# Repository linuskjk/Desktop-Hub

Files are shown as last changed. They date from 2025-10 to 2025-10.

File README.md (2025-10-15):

# Desktop Hub

What this project is
--------------------
This project is a compact desktop USB 2.0 hub built around the GL852G hub controller. It gives you:
- One USB-C upstream port (to connect to a host)
- Two USB-A downstream ports plus one USB-C downstream port
- Per-port power switches (TPS2051C) to protect and limit current to each downstream port
- ESD protection on USB data and power lines

Why I want to build it   I-
----------------------
- Want a small, DIY USB hub for flash drives, keyboards, mice, and low-power peripherals
- Need a hub you can modify (change ESD parts, use different power switches, or tweak traces for higher current)
- Learn about hub controllers, USB signal routing, and SMD assembly

Quick features and limits
-------------------------
- USB 2.0 data speeds supported (Full Speed/High Speed up to USB 2.0 limits)
- Signal traces for D+/D− are routed at 0.2 mm (fine and short — good for USB 2.0)
- VBUS/GND are routed at 0.2 mm in this version due to spacing problems— suitable for flash drives and low-current devices; phone charging will be limited

Licensing
---------
This project is released under the MIT License.

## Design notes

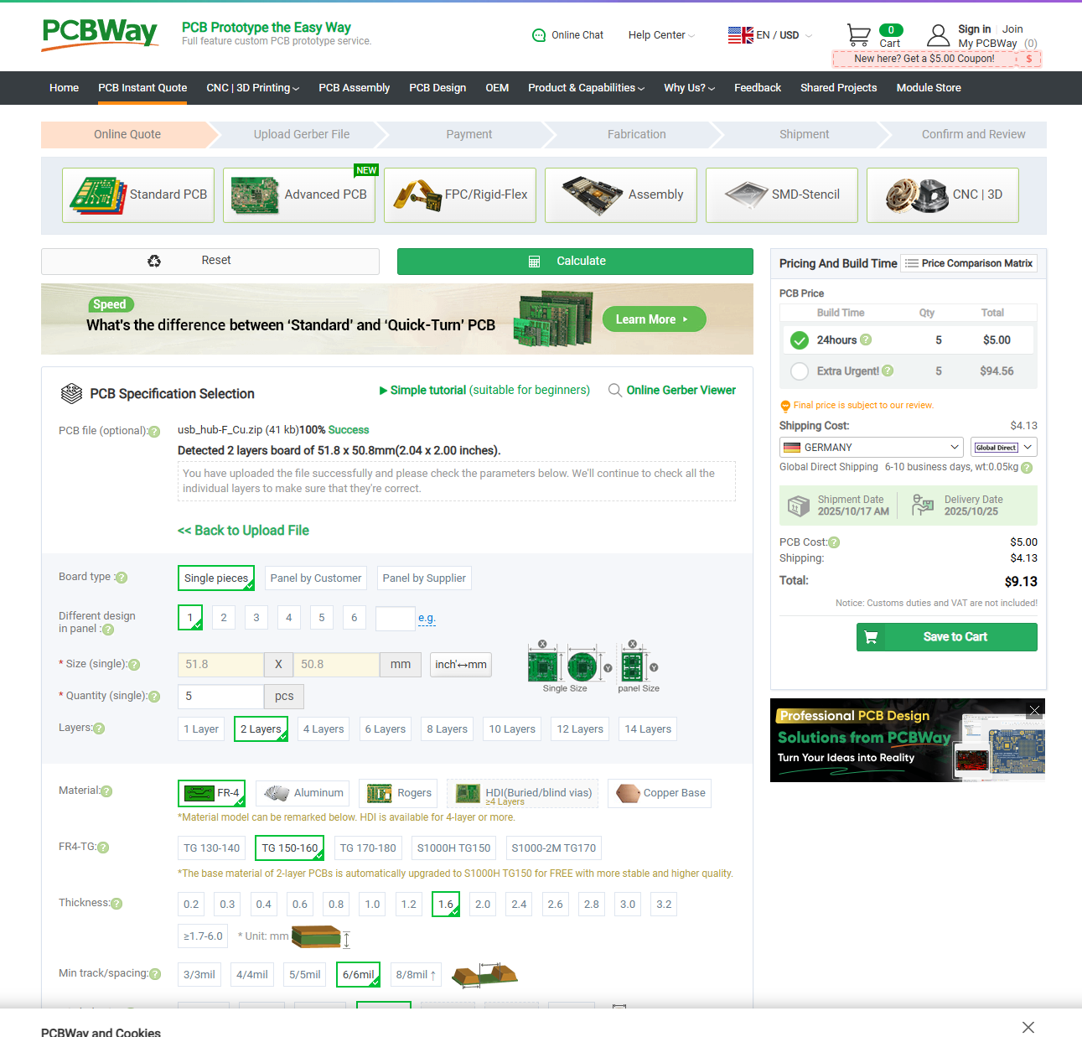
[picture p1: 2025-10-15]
price screenshots/pcb.png

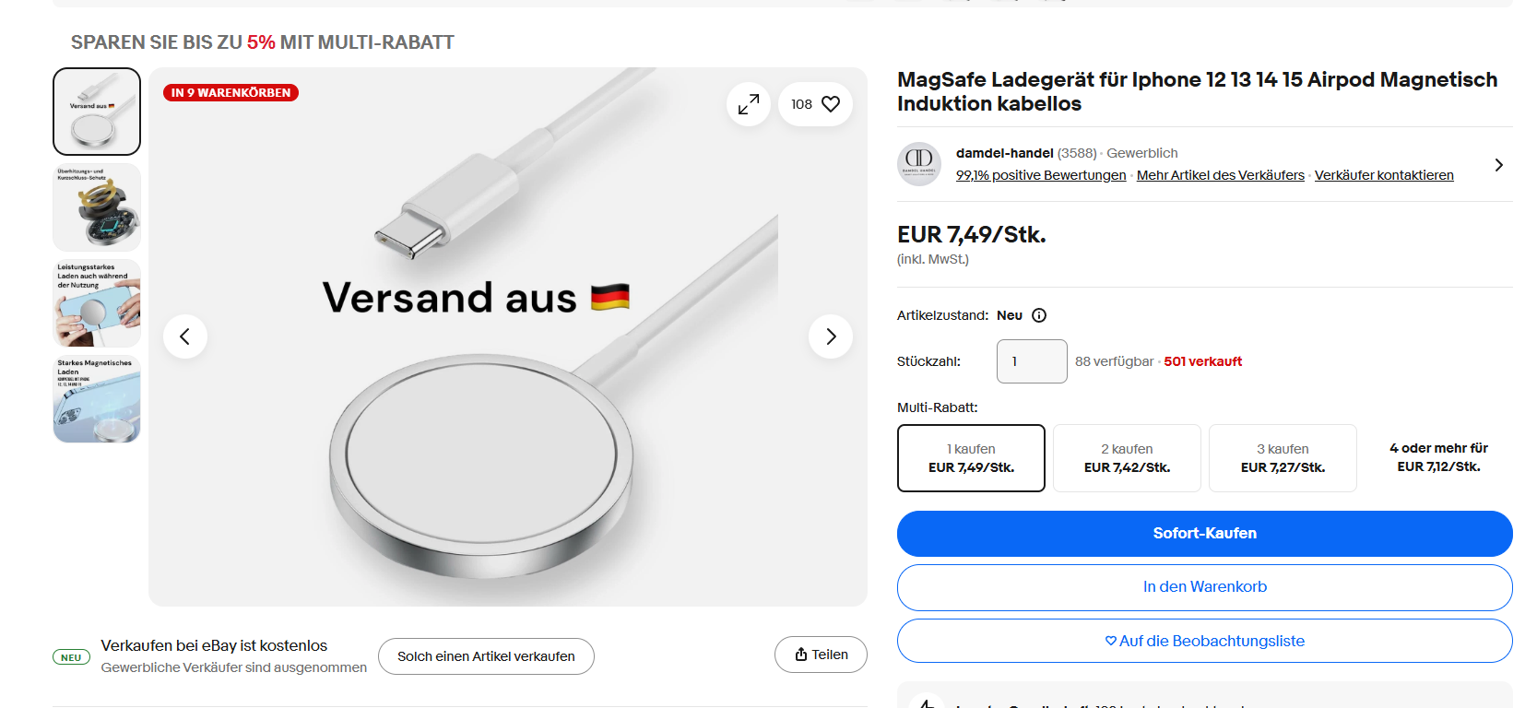
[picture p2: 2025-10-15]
price screenshots/magsafe.png

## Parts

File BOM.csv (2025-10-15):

Reference | Qty | Value / Description | DNP | Exclude from BOM | Exclude from Board | Footprint | Datasheet | Notes
C1 | 1 | 10uF |  |  |  | Capacitor_SMD:C_0805_2012Metric_Pad1.18x1.45mm_HandSolder | ~ | As on schematic
C2 | 1 | 0.1uF |  |  |  | Capacitor_SMD:C_0805_2012Metric_Pad1.18x1.45mm_HandSolder | ~ | As on schematic
C3 | 1 | 1uF |  |  |  | Capacitor_SMD:C_0603_1608Metric_Pad1.08x0.95mm_HandSolder | ~ | As on schematic
C4 | 1 | 10uF |  |  |  | Capacitor_SMD:C_0805_2012Metric_Pad1.18x1.45mm_HandSolder | ~ | As on schematic
C5,C7,C9,C12,C13,C14,C15,C16,C17,C18,C19,C20,C21,C22,C23 | 15 | 0.1uF |  |  |  | Capacitor_SMD:C_0603_1608Metric_Pad1.08x0.95mm_HandSolder | ~ | Bulk decoupling
C6,C8 | 2 | 0.1uF |  |  |  | Capacitor_SMD:C_0805_2012Metric_Pad1.18x1.45mm_HandSolder | ~ | As on schematic
C10,C11 | 2 | 222pF |  |  |  | Capacitor_SMD:C_0603_1608Metric_Pad1.08x0.95mm_HandSolder | ~ | Crystal loading
F1 | 1 | Polyfuse 1206 |  |  |  | Fuse:Fuse_1206_3216Metric_Pad1.42x1.75mm_HandSolder | ~ | VBUS overcurrent protection
FB1 | 1 | Ferrite Bead 0805 |  |  |  | Inductor_SMD:L_0805_2012Metric_Pad1.15x1.40mm_HandSolder | ~ | EMI on VBUS
H1 | 1 | MountingHole |  | Excluded from BOM |  |  |  | Mechanical hole (NPTH)
J1,J2 | 2 | USB_C_Receptacle_USB2.0_16P |  |  |  | Connector_USB:USB_C_Receptacle_HRO_TYPE-C-31-M-12 | https://www.usb.org/sites/default/files/documents/usb_type-c.zip | Upstream and downstream USB-C
J3,J4 | 2 | USB_A |  |  |  | Connector_USB:USB_A_Stewart_SS-52100-001_Horizontal | ~ | USB-A downstream ports
R1,R2,R7,R8 | 4 | 5.1k |  |  |  | Resistor_SMD:R_0603_1608Metric_Pad0.98x0.95mm_HandSolder | ~ | Pull-downs/dividers
R3,R4,R9,R10,R11,R12,R13,R14 | 8 | 27 |  |  |  | Resistor_SMD:R_0603_1608Metric_Pad0.98x0.95mm_HandSolder | ~ | Pull-downs
R5 | 1 | 12k |  |  |  | Resistor_SMD:R_0603_1608Metric_Pad0.98x0.95mm_HandSolder | ~ | Net resistors
R6 | 1 | 10k |  |  |  | Resistor_SMD:R_0603_1608Metric_Pad0.98x0.95mm_HandSolder | ~ | Pull-up
U1,U7,U8,U9 | 4 | USBLC6-2SC6 (ESD Diode) |  |  |  | Package_TO_SOT_SMD:SOT-23-6 | https://www.st.com/resource/en/datasheet/usblc6-2.pdf | USB ESD protection
U2 | 1 | AP2112K-3.3 (LDO) |  |  |  | Package_TO_SOT_SMD:SOT-23-5 | https://www.diodes.com/assets/Datasheets/AP2112.pdf | 3.3V regulator
U3,U4 | 2 | TPS2051CDBV (USB power switch) |  |  |  | Package_TO_SOT_SMD:SOT-23-5 | https://www.ti.com/lit/ds/symlink/tps2051c.pdf | Per-port power switch
U5 | 1 | GL852G (LQFP-48) hub controller |  |  |  | Package_QFP:LQFP-48_7x7mm_P0.5mm |  | Verify footprint and paste
U6 | 1 | TPS2051CDBV (USB power switch) |  |  |  | Package_TO_SOT_SMD:SOT-23-5_HandSoldering | https://www.ti.com/lit/ds/symlink/tps2051c.pdf | Per-port power switch
Y1 | 1 | 12MHz Crystal 5032 |  |  |  | Crystal:Crystal_SMD_5032-2Pin_5.0x3.2mm_HandSoldering | ~ | Hub clock
# Additional non-PCB items and accessories (not mounted on PCB)
USB-C upstream cable | 1 | USB-C to USB-A (or C-to-C) cable |  | Exclude from BOM |  | Cable | ~ | Use appropriate cable for host connection (choose C-to-C for modern hosts)
MagSafe adapter (external) | 1 | Apple MagSafe adapter or magnetic power adapter (optional) |  | Exclude from BOM |  | Accessory | ~ | Optional external magnetic power adapter; verify model compatibility – not a PCB part
5V DC power adapter (optional) | 1 | 5V 2A power supply (if using external power) |  | Exclude from BOM |  | Accessory | ~ | Optional external power supply for VBUS when used standalone

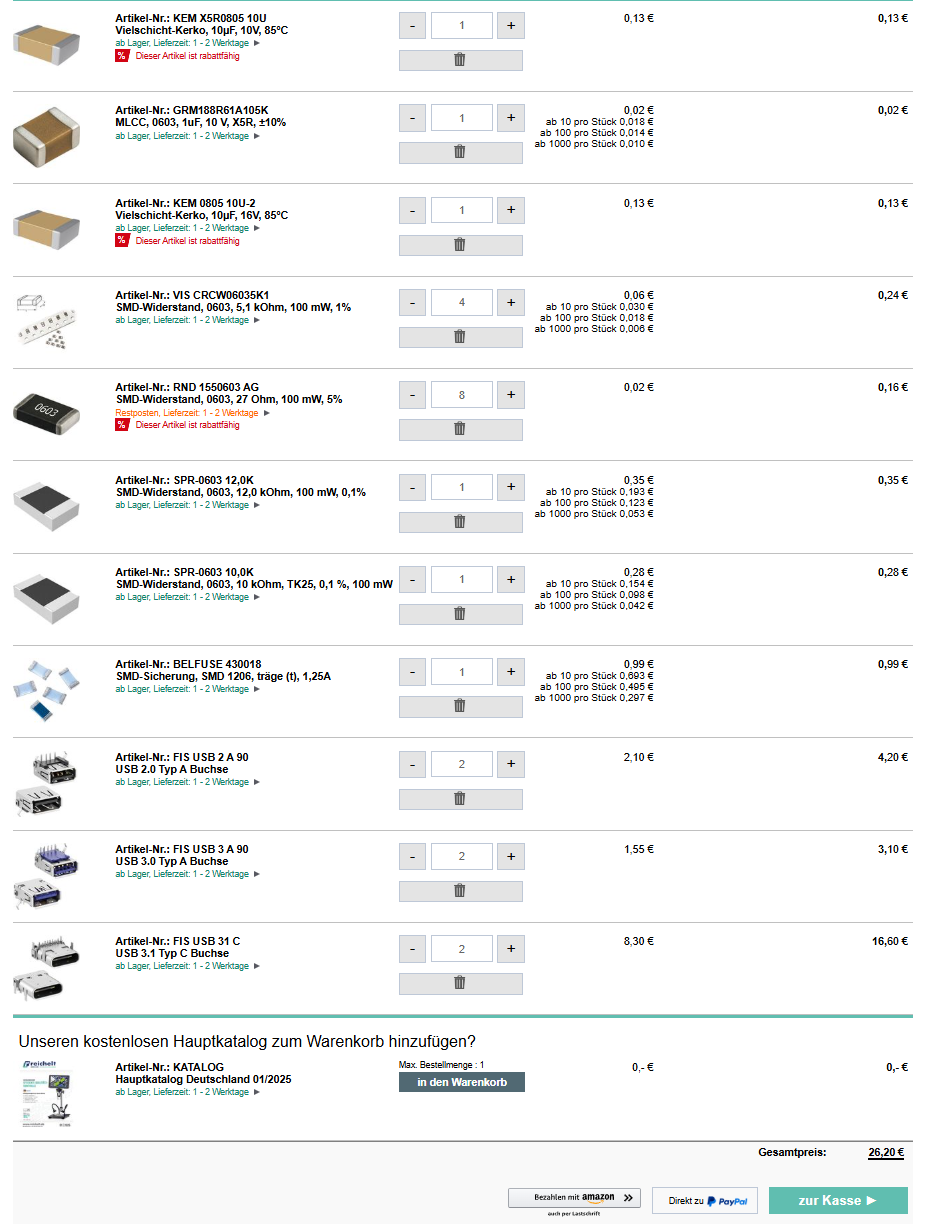
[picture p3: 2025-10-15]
price screenshots/pcb-parts-1.png

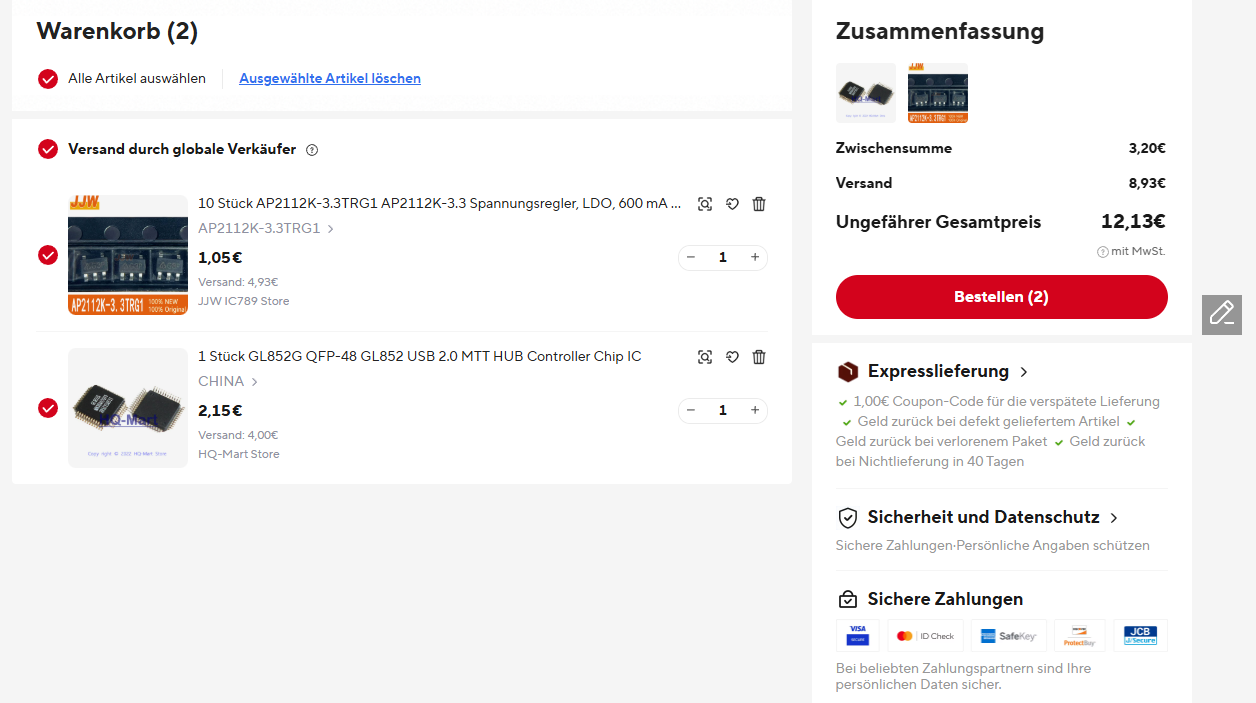
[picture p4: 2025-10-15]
price screenshots/pcb-parts-2.png

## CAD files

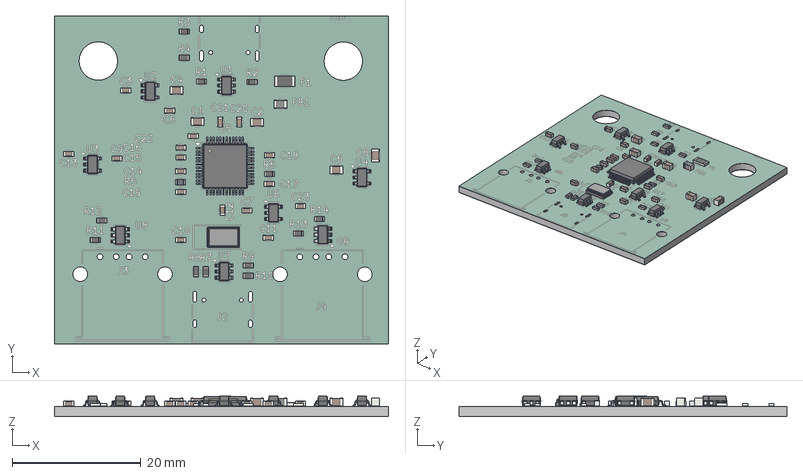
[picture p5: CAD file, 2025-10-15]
pcb.step
51.8 x 50.8 x 3.19 mm
C_0603_1608Metric x 18
R_0603_1608Metric x 14
Crystal_SMD_5032-2Pin_5.0x3.2mm
SOT-23-5 x 4
L_0805_2012Metric
C_0805_2012Metric x 5
SOT-23-6 x 4
LQFP-48_7x7mm_P0.5mm
Fuse_1206_3216Metric
usb_hub_silkscreen
usb_hub_soldermask x 2
usb_hub_PCB

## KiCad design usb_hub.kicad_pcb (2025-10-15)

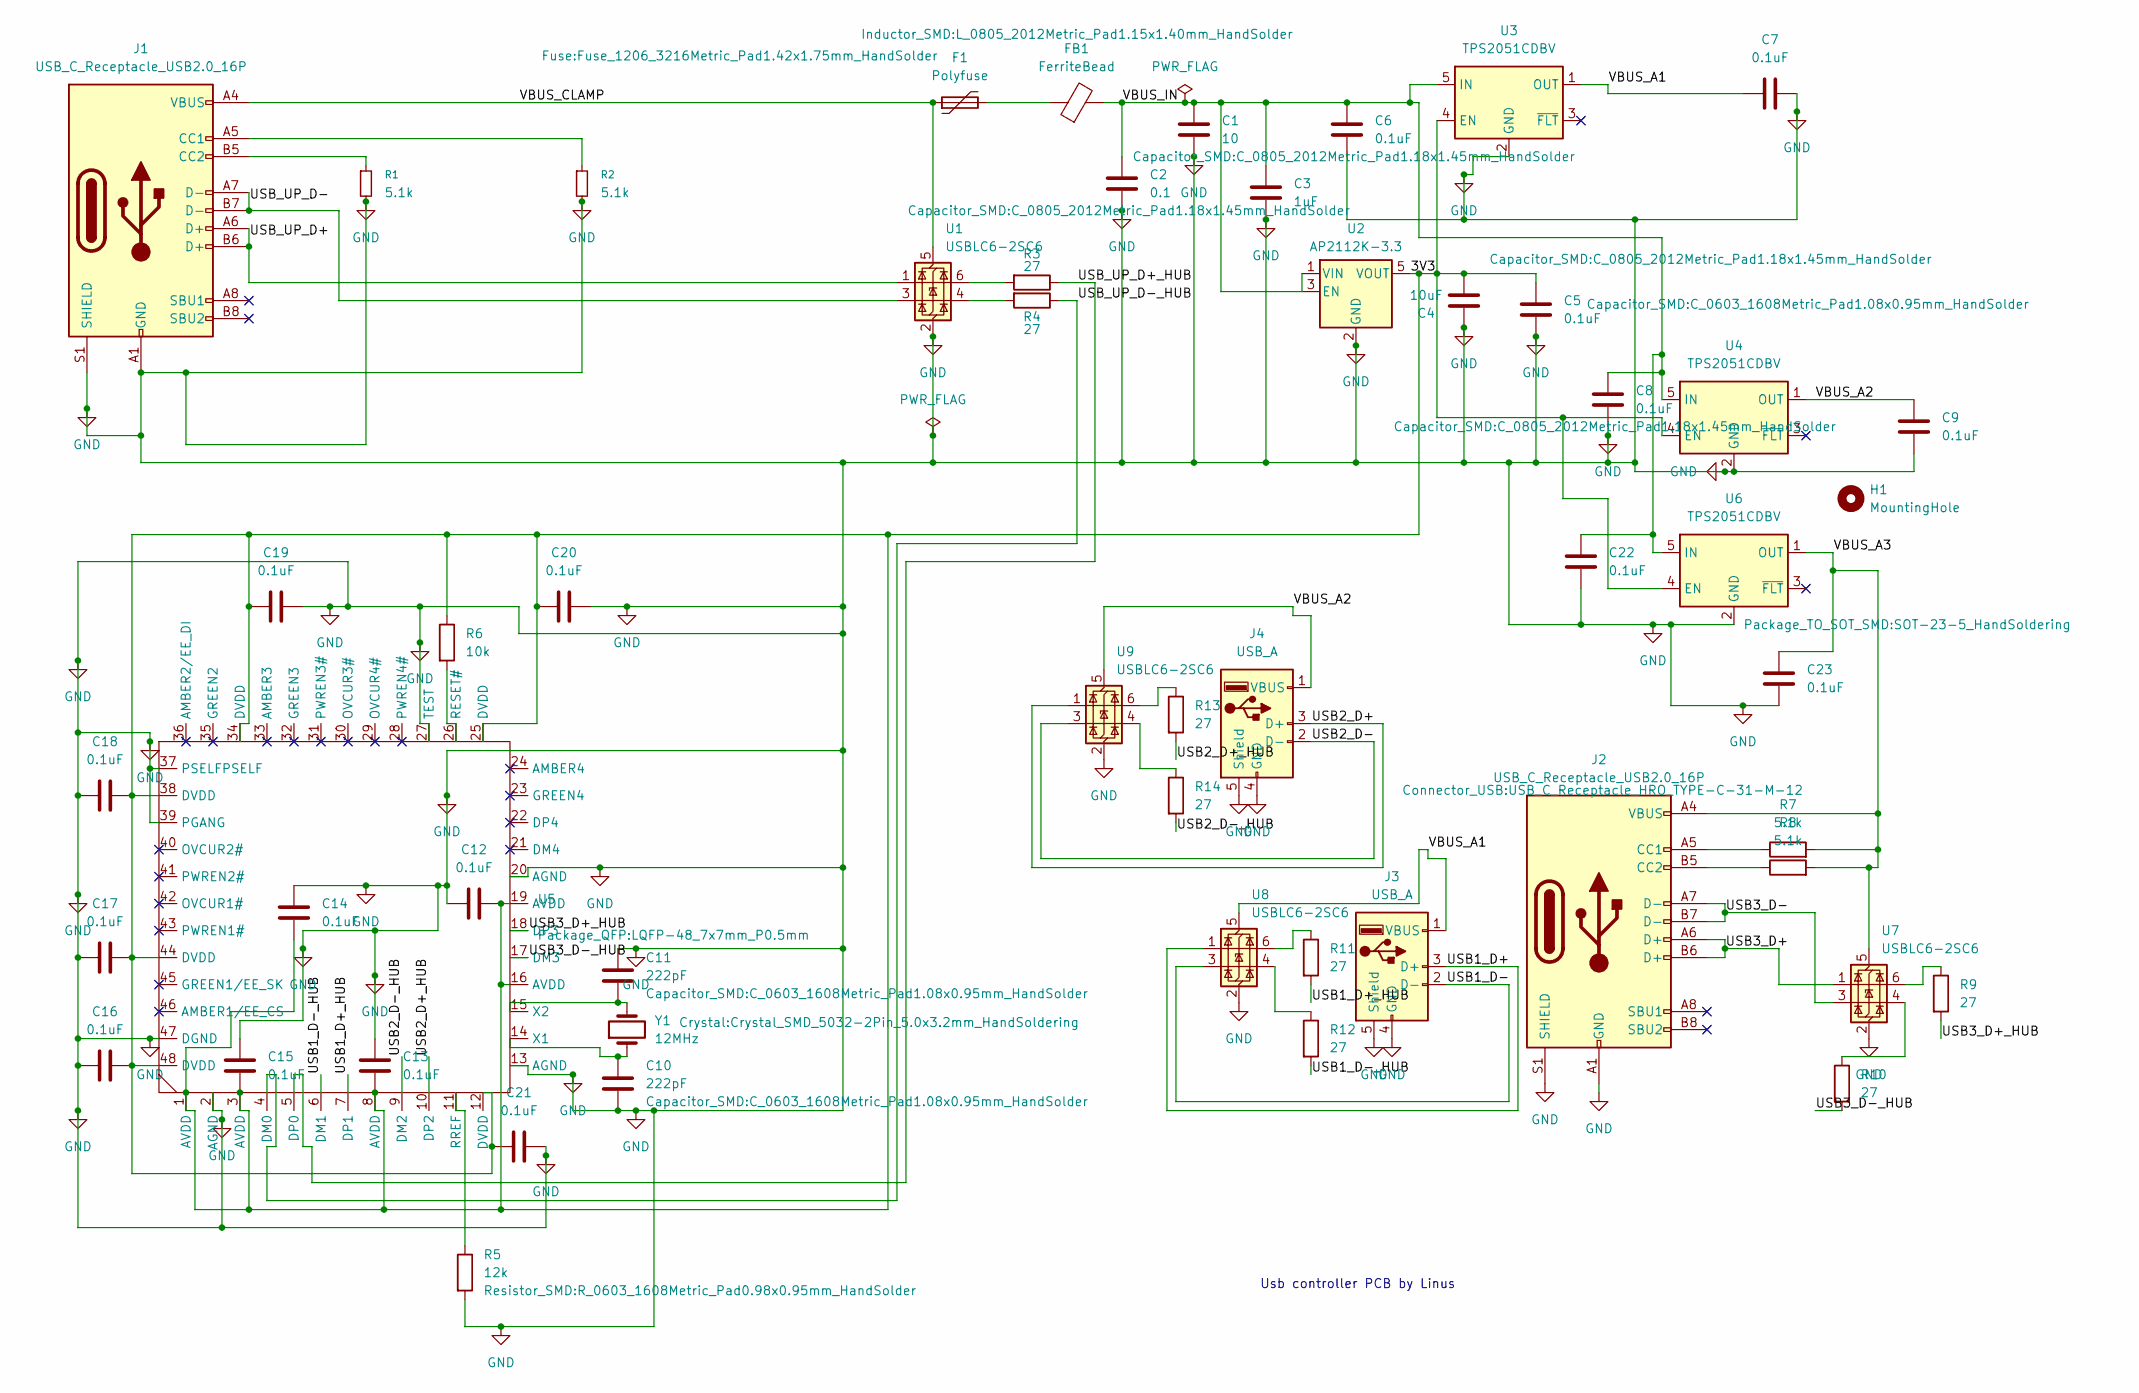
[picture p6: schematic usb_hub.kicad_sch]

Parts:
C1: 10; C_0805_2012Metric_Pad1.18x1.45mm_HandSolder
C2: 0.1; C_0805_2012Metric_Pad1.18x1.45mm_HandSolder
C3: 1uF; C_0603_1608Metric_Pad1.08x0.95mm_HandSolder
C4: 10uF; C_0805_2012Metric_Pad1.18x1.45mm_HandSolder
C5, C7, C9, C12, C13, C14, C15, C16, C17, C18, C19, C20, C21, C22, C23: 0.1uF; C_0603_1608Metric_Pad1.08x0.95mm_HandSolder
C6, C8: 0.1uF; C_0805_2012Metric_Pad1.18x1.45mm_HandSolder
C10, C11: 222pF; C_0603_1608Metric_Pad1.08x0.95mm_HandSolder
F1: Polyfuse; Fuse_1206_3216Metric_Pad1.42x1.75mm_HandSolder
FB1: FerriteBead; L_0805_2012Metric_Pad1.15x1.40mm_HandSolder
H1: MountingHole
J1, J2: USB_C_Receptacle_USB2.0_16P; USB_C_Receptacle_HRO_TYPE-C-31-M-12
J3, J4: USB_A; USB_A_Stewart_SS-52100-001_Horizontal
R1, R2, R7, R8: 5.1k; R_0603_1608Metric_Pad0.98x0.95mm_HandSolder
R3, R4, R9, R10, R11, R12, R13, R14: 27; R_0603_1608Metric_Pad0.98x0.95mm_HandSolder
R5: 12k; R_0603_1608Metric_Pad0.98x0.95mm_HandSolder
R6: 10k; R_0603_1608Metric_Pad0.98x0.95mm_HandSolder
U1, U7, U8, U9: USBLC6-2SC6; SOT-23-6
U2: AP2112K-3.3; SOT-23-5
U3, U4: TPS2051CDBV; SOT-23-5
U5: LQFP-48_7x7mm_P0.5mm
U6: TPS2051CDBV; SOT-23-5_HandSoldering
Y1: 12MHz; Crystal_SMD_5032-2Pin_5.0x3.2mm_HandSoldering

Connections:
/3V3: C4.2, C5.1, C12.2, C13.1, C14.1, C15.1, C16.2, C17.2, C18.2, C19.2, C20.1, C21.1, R6.1, U2.5 (VOUT), U3.4 (EN), U4.4 (EN), U5.1 (AVDD), U5.3 (AVDD), U5.8 (AVDD), U5.12 (DVDD), U5.16 (AVDD), U5.19 (AVDD), U5.25 (DVDD), U5.34 (DVDD), U5.38 (DVDD), U5.44 (DVDD), U5.48 (DVDD), U6.4 (EN)
/USB1_D+: J3.3 (D+), U8.1 (I/O1)
/USB1_D+_HUB: R11.2, U5.7 (DP1)
/USB1_D-: J3.2 (D-), U8.3 (I/O2)
/USB1_D-_HUB: R12.2, U5.6 (DM1)
/USB2_D+: J4.3 (D+), U9.1 (I/O1)
/USB2_D+_HUB: R13.2, U5.10 (DP2)
/USB2_D-: J4.2 (D-), U9.3 (I/O2)
/USB2_D-_HUB: R14.2, U5.9 (DM2)
/USB3_D+: J2.A6 (D+), J2.B6 (D+), U7.1 (I/O1)
/USB3_D+_HUB: R9.2, U5.18 (DP3)
/USB3_D-: J2.A7 (D-), J2.B7 (D-), U7.3 (I/O2)
/USB3_D-_HUB: R10.2, U5.17 (DM3)
/USB_UP_D+: J1.A6 (D+), J1.B6 (D+), U1.1 (I/O1)
/USB_UP_D+_HUB: R3.1, U5.5 (DP0)
/USB_UP_D-: J1.A7 (D-), J1.B7 (D-), U1.3 (I/O2)
/USB_UP_D-_HUB: R4.1, U5.4 (DM0)
/VBUS_A1: C7.2, J3.1 (VBUS), U3.1 (OUT), U8.5 (VBUS)
/VBUS_A2: C9.2, J4.1 (VBUS), U4.1 (OUT), U9.5 (VBUS)
/VBUS_A3: C23.1, J2.A4 (VBUS), J2.A9 (VBUS), J2.B4 (VBUS), J2.B9 (VBUS), R7.2, R8.2, U6.1 (OUT), U7.5 (VBUS)
/VBUS_CLAMP: F1.1, J1.A4 (VBUS), J1.A9 (VBUS), J1.B4 (VBUS), J1.B9 (VBUS), U1.5 (VBUS)
/VBUS_IN: C1.2, C2.1, C3.1, C6.1, C8.1, C22.1, FB1.2, U2.1 (VIN), U2.3 (EN), U3.5 (IN), U4.5 (IN), U6.5 (IN)
GND: C1.1, C2.2, C3.2, C4.1, C5.2, C6.2, C7.1, C8.2, C9.1, C10.2, C11.1, C12.1, C13.2, C14.2, C15.2, C16.1, C17.1, C18.1, C19.1, C20.2, C21.2, C22.2, C23.2, J1.A1 (GND), J1.A12 (GND), J1.B1 (GND), J1.B12 (GND), J1.S1 (SHIELD), J2.A1 (GND), J2.A12 (GND), J2.B1 (GND), J2.B12 (GND), J2.S1 (SHIELD), J3.4 (GND), J3.5 (Shield), J4.4 (GND), J4.5 (Shield), R1.2, R2.2, R5.2, U1.2 (GND), U2.2 (GND), U3.2 (GND), U4.2 (GND), U5.2 (AGND), U5.13 (AGND), U5.20 (AGND), U5.27 (TEST), U5.37 (PSELFPSELF), U5.39 (PGANG), U5.47 (DGND), U6.2 (GND), U7.2 (GND), U8.2 (GND), U9.2 (GND)
unnamed: F1.2, FB1.1
unnamed: J1.A5 (CC1), R2.1
unnamed: J1.B5 (CC2), R1.1
unnamed: J2.A5 (CC1), R7.1
unnamed: J2.B5 (CC2), R8.1
unnamed: R3.2, U1.6 (I/O1)
unnamed: R4.2, U1.4 (I/O2)
unnamed: R9.1, U7.6 (I/O1)
unnamed: R10.1, U7.4 (I/O2)
unnamed: R11.1, U8.6 (I/O1)
unnamed: R12.1, U8.4 (I/O2)
unnamed: R13.1, U9.6 (I/O1)
unnamed: R14.1, U9.4 (I/O2)
unnamed: R6.2, U5.26 (RESET#)
unnamed: R5.1, U5.11 (RREF)
unnamed: C10.1, U5.14 (X1), Y1.1
unnamed: C11.2, U5.15 (X2), Y1.2

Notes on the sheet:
Usb controller PCB by Linus

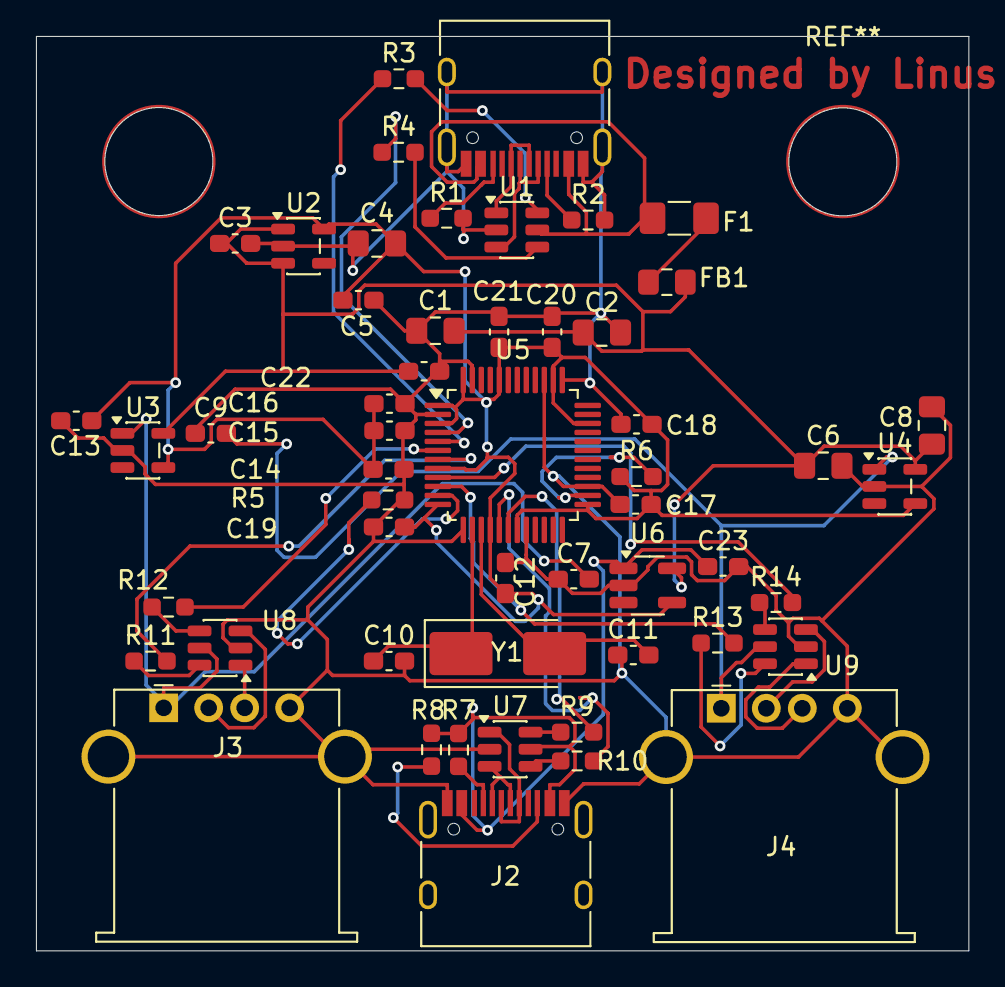
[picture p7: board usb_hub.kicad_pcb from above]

Board: 2 copper layers, 51.8 x 50.8 mm, 53 parts (0 on the bottom side), 40 nets.

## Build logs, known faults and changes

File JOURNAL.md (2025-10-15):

<!--
  ===================    !!READ THIS NOTICE!!   ====================
  DO NOT edit this file manually. Your changes WILL BE OVERWRITTEN!
  This journal is auto generated and updated by Hack Club Blueprint.
  To edit this file, please edit your journal entries on Blueprint.
  ==================================================================
-->

This is my journal of the design and building process of **Desktop Hub**.  
You can view this journal in more detail on **Hack Club Blueprint** [here](https://blueprint.hackclub.com/projects/197).

## 10/5/2025 2 PM - Got Idea and created basic PCB  

I thought about some useful projects I could do and came up with this.
A charger for your phone and other devices and some usb-a ports would be quite useful on my desktio.
So I painted some prototypes in paint and then realized, that the hardest part is propably gonna be creating the PCB. I started with the PCB as you can see in the Image.

## 10/5/2025 10 PM - Worked on schematic for pcb  

I worked on the PCB creation a Power Protection to the circuit so that if you would put too much power on the usb-c port the chips wont fry. I also added an ESD protection to protect the powerlines of the usb-a ports that you can use for your flash drives.



## 10/6/2025 - Symbol creation for pcb  

I again worked on the pcb and added the Power Switches for the usb-a ports and all that comes with that.
After that I worked on my own symbol, because it doesn't exist yet so I'm working on creating the 48pin chip only got one of the 4 sides done but in the future working on all others.



## 10/11/2025 12 AM - Finishing Schematic of PCB  

This was a quite challenging part.
Firstly I want to use multiple USB-Ports at simultaneously so we need a controller to control those ports. The problem is, that there were only Chinese datasheets for the chip I use so I had to manually translate the datasheet. After that I had to create the chip myself as a symbol in KiCAD which is quite time consuming. When I was done with that, I had to wire all those pins up and place a bunch of resistors and capacitors. Now I also added the USB-A ports and a USB-C port to the schematic so it is basically done. Next thing will be routing and defining the PCB and all...





## 10/11/2025 10 PM - Aligned the components and started routing the GND and VBUS  

It took me about 2.5 hours to align all the components correctly, while ensuring the capacitors and resistors were close enough to their connectors. Finally, the layout is perfect (USB-C for upstream on the back and 2xUSB-A & 1xUSB-C on the front for downstream).
I've also started routing the ground and VBUS pins.
Now I'm routing all the other pins and fixing, what comes with it.



## 10/15/2025 1 PM - Routed the PCB  

After some time, I've finished routing the circuit board. The main challenge was ensuring the correct track width for the charging ports so that they can be used for fast charging. Now I'm going to prepare the housing for the PCB and the MagSafe charger so that you can charge your devices wirelessly.



## 10/15/2025 5 PM - Created 3D model for the Case  

After completing the circuit board, I created the 3D model of the case in Fusion. I added holes for the connectors on the front panel. I also created some brackets for the circuit board. To make the whole thing more manageable, I implemented some cable holders. I designed it as minimalistic as possible. 
